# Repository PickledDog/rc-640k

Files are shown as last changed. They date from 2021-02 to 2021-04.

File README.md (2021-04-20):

# rc-640k
 128K+512K RAM/ROM card for RC2014
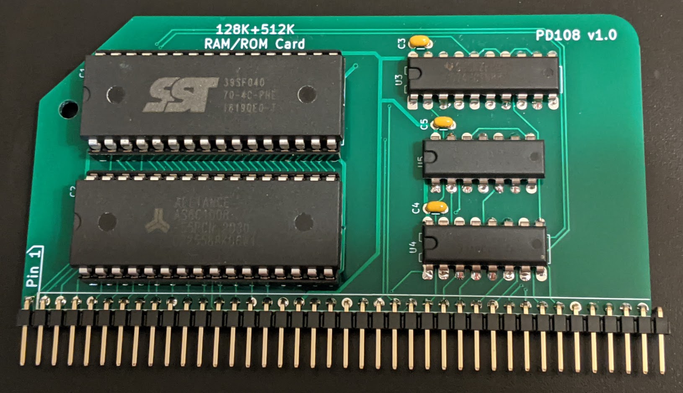
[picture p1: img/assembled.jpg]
Assembled PD108


## Overview
This RC2014-compatible board provides RAM and flash ROM, software-pageable in 32k pages. 16 ROM or 4 RAM pages may be paged into the lower 32k of Z80 memory. This paging scheme is compatible with Wayne Warthen's [RomWBW](https://github.com/wwarthen/RomWBW).

## Memory details
For ROM, a SST39SF040 512k x 8 flash chip is used. It can be programmed in-place using Will Sowerbutts' FLASH4 utility (included with RomWBW). For RAM, an AS6C1008 128k x 8 SRAM is used, providing 128K of addressable memory. Both are divided into 32k pages, and any page of either chip can be paged into the lower 32k of the address space. The upper 32k is permanently mapped to the last page of the RAM chip.

## Paging
Upon reset, the first page of the ROM is mapped to the lower 32k. If left alone, the board will behave like any 32k ROM+32k RAM RC2014 system. A config register is used to set the currently mapped page, presented as an I/O device at 0x78 (the address used by most "large" Z80 memory systems). The low nibble sets the page number (0-15 for ROM, 0-3 for RAM), and high bit 7 selects the chip (0 for ROM, 1 for RAM).

The port address and layout are chosen to be (mostly) compatible with the [RetroBrew SBC](https://www.retrobrewcomputers.org/doku.php?id=boards:sbc:sbc_v2:sbc_v2-003). The SBC has separate ROM and RAM registers (on 0x78 and 0x7C); this board uses a single register for both, which can be written to from either address.

## Firmware
Many [RC2014 ROM images](https://github.com/RC2014Z80/RC2014/tree/master/ROMs) can be used (selecting the right image for your serial board), but some will require modification to accommodate the different paging system. The 32k BASIC images work unmodified. Stephen C Cousins' excellent [Small Computer Monitor](https://smallcomputercentral.wordpress.com/small-computer-monitor/) can be used as well - choose the R3 configuration. CP/M loading *won't work* without code changes.

But most importantly, this board is compatible with [RomWBW](https://github.com/wwarthen/RomWBW), providing several CP/M versions, ROM applications, and maximized free application memory. It will need to be built from source with configuration changes, although this is fairly straightforward (RomWBW includes its entire build toolchain in the source tree). The build process is covered in [this page](https://github.com/wwarthen/RomWBW/blob/master/Source/ReadMe.txt) from the RomWBW documentation (including Linux and Mac instructions). An example image can be found in the [firmware](/firmware) directory.

### RomWBW Config changes
With the [source tree](https://github.com/wwarthen/RomWBW) unpacked, go into `Source/HBIOS/Config` and make a copy of `RCZ80_std.asm` (call it `RCZ80_pd.asm`). Edit this new file, and add the following lines:
```
RAMSIZE		.SET	128		; SIZE OF RAM IN KB (MUST MATCH YOUR HARDWARE!!!)
MEMMGR		.SET	MM_SBC		; MEMORY MANAGER: MM_[SBC|Z2|N8|Z180]
MPCL_RAM	.EQU	$78		; SBC MEM MGR RAM PAGE SELECT REG (WRITE ONLY)
MPCL_ROM	.EQU	$7C		; SBC MEM MGR ROM PAGE SELECT REG (WRITE ONLY)
;
```
As of RomWBW 3.1, it is possible to have a ROMdisk without a RAMdisk (which this board does not support). If building RomWBW 3.1 or later, add this line too: 
```
MDRAM		.SET	FALSE		; MD: DISABLE RAM DISK
;
```
With our new file, we can go ahead and build our ROM image. Under Windows, this is done with the following commands in `Source`:

* `BuildShared`
  * Wait for this to complete, ignoring the harmless program origin warnings
* `BuildROM`
  * Enter `RCZ80` at the *Platform* prompt
  * Enter `pd` at the *Configuration* prompt

Once the build is complete, we are done! Back at the root of the source tree, go into `Binary` and retrieve our new `RCZ80_pd.rom`. This can now be burned to the flash chip using an EPROM programmer, such as a [TL866](https://www.ebay.com/sch/i.html?_nkw=tl866ii+plus).

## Part selection
Bill Of Materials and part references are below. I recommend using gold-plated header for the bus connection - I use these ones from [Pololu](https://www.pololu.com/product/967) or [Sparkfun](https://www.sparkfun.com/products/553). A nice detail of these, is that they sit at the same height as double-row header in a backplane.

The specified parts are just the ones I used, and can be substituted as needed - Mouser links provided for convenience and reference.

| Reference | Value | Qty | Mouser link |
| --- | ----- | --- | --- |
| C1-C5 | 100nF ceramic | 5 | [KEMET C315C104M5U5TA](https://www.mouser.com/ProductDetail/C315C104M5U5TA7303) |
| J1 | 1x40 right-angle header | 1 | [Wurth 61304011021](https://www.mouser.com/ProductDetail/61304011021) |
| U1 | SST39SF040 NOR flash | 1 | [Microchip SST39SF040-70-4C-PHE](https://www.mouser.com/ProductDetail/SST39SF040-70-4C-PHE) |
| U2 | AS6C1008 SRAM | 1 | [Alliance AS6C1008-55PCN](https://www.mouser.com/ProductDetail/AS6C1008-55PCN) |
| | sockets | 2 | [Amphenol DILB32P-223TLF](https://www.mouser.com/ProductDetail/DILB32P-223TLF) |
| U3 | 74HCT688 | 1 | [TI CD74HCT688E](https://www.mouser.com/ProductDetail/CD74HCT688E) |
| U4 | 74HCT174 | 1 | [TI CD74HCT174E](https://www.mouser.com/ProductDetail/CD74HCT174E) |
| U5 | 74HCT32 | 1 | [TI SN74HCT32N](https://www.mouser.com/ProductDetail/SN74HCT32N) |

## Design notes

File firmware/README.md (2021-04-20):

# Firmware
This directory contains firmware source and binary for the board. As of now, it currently only contains a RomWBW image and the config file used to make it. It is currently built against RomWBW 3.1.1-pre.71.

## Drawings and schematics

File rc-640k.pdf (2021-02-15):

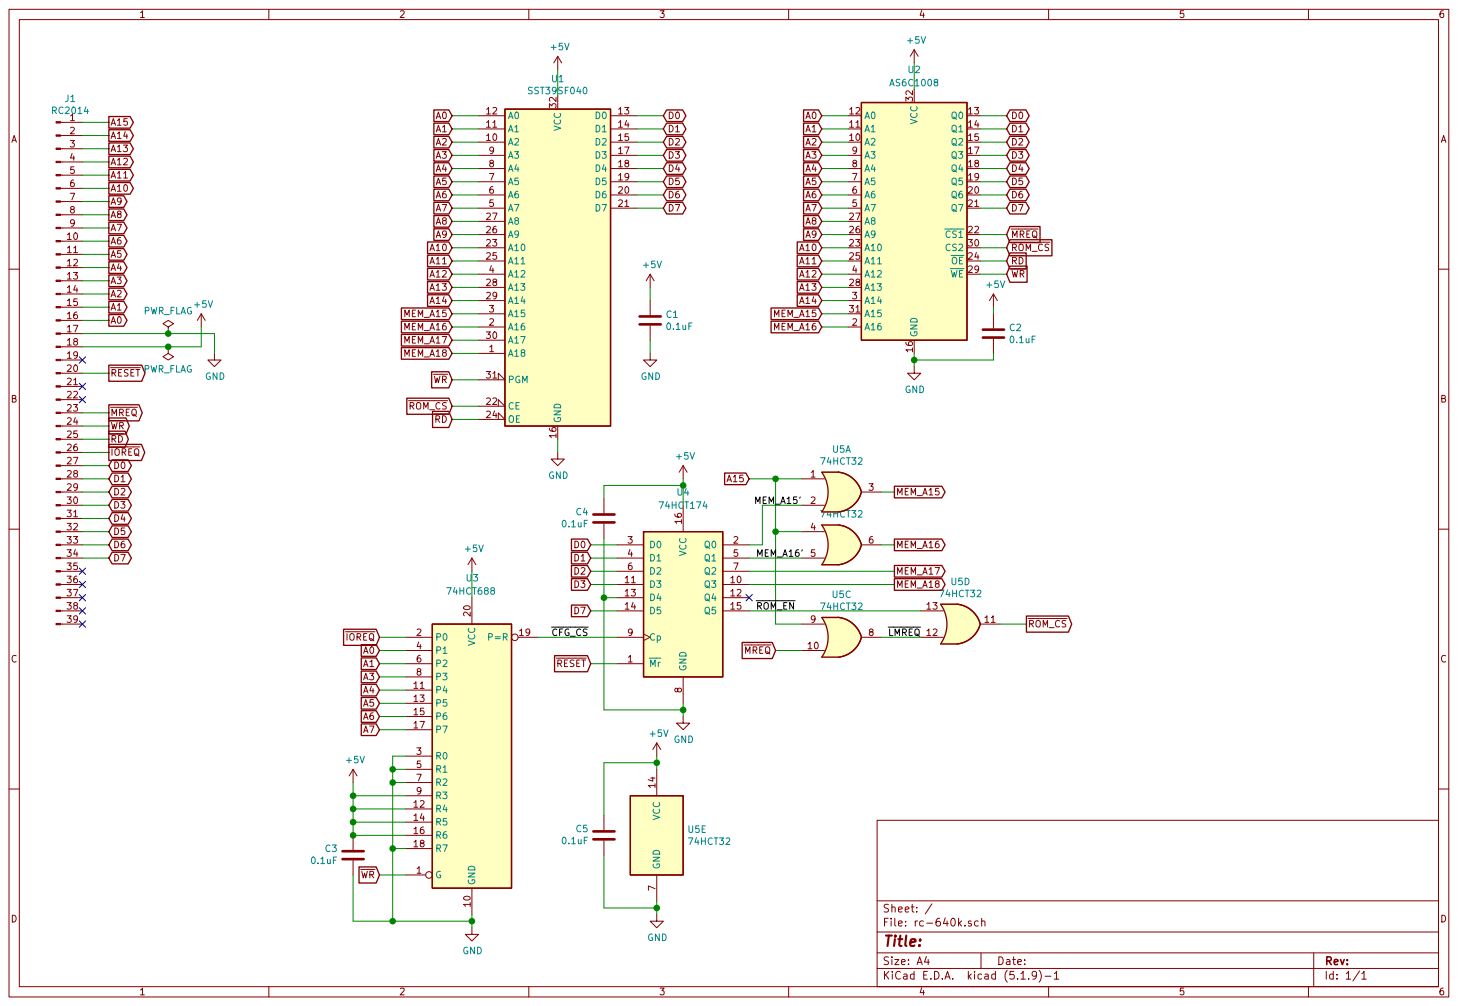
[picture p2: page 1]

Id: 1/1 Title: File: rc-640k.sch Sheet: / GND

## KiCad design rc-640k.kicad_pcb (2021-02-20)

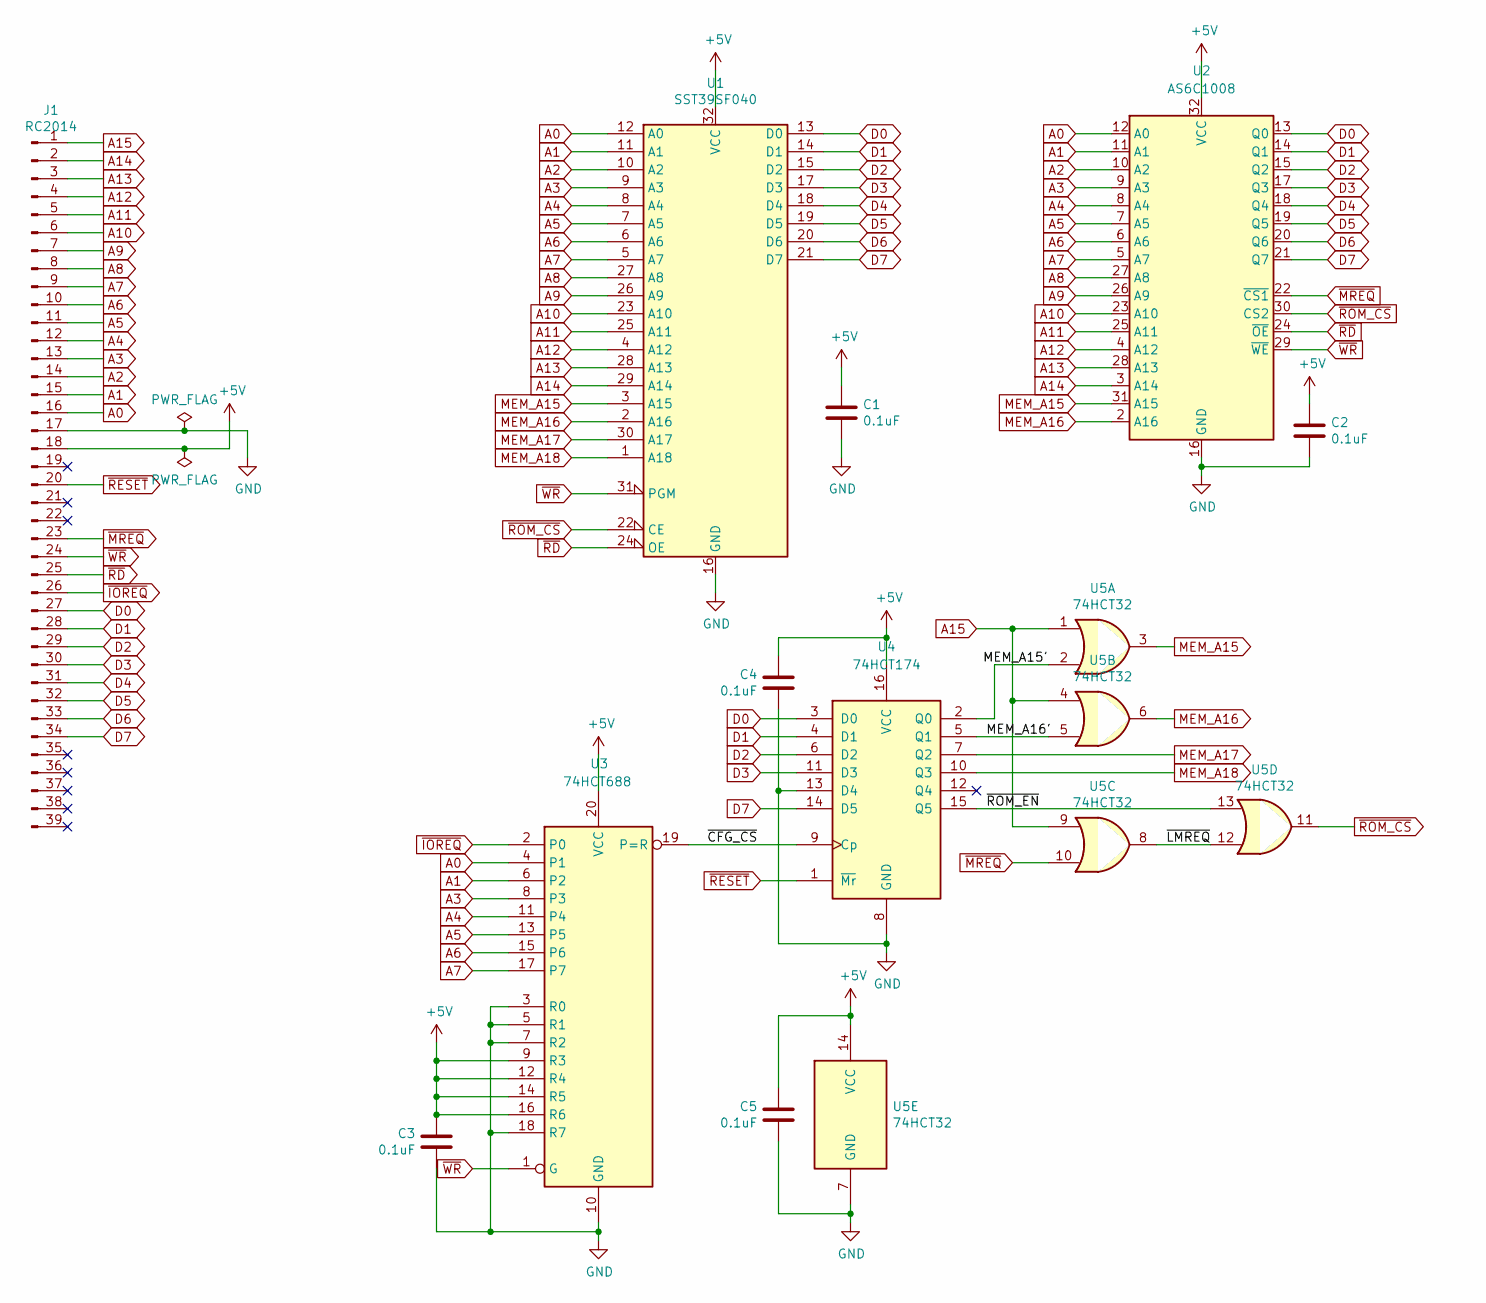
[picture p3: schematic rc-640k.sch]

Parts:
C1, C2, C3, C4, C5: 0.1uF; C_Disc_D3.0mm_W1.6mm_P2.50mm
J1: RC2014; PinHeader_1x39_P2.54mm_Vertical
U1: SST39SF040; DIP-32_W15.24mm_LongPads
U2: AS6C1008; DIP-32_W15.24mm_LongPads
U3: 74HCT688; DIP-20_W7.62mm_LongPads
U4: 74HCT174; DIP-16_W7.62mm_LongPads
U5: 74HCT32; DIP-14_W7.62mm_LongPads

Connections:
+5V: C1.1, C2.1, C3.2, C4.2, C5.2, J1.18, U1.32 (VCC), U2.32 (VCC), U3.9 (R3), U3.12 (R4), U3.14 (R5), U3.16 (R6), U3.20 (VCC), U4.16 (VCC), U5.14 (VCC)
/MEM_A15': U4.2 (Q0), U5.2
/MEM_A16': U4.5 (Q1), U5.5
/~CFG_CS: U3.19 (P=R), U4.9 (Cp)
/~LMREQ: U5.8, U5.12
/~ROM_EN: U4.15 (Q5), U5.13
A0: J1.16, U1.12 (A0), U2.12 (A0), U3.4 (P1)
A1: J1.15, U1.11 (A1), U2.11 (A1), U3.6 (P2)
A2: J1.14, U1.10 (A2), U2.10 (A2)
A3: J1.13, U1.9 (A3), U2.9 (A3), U3.8 (P3)
A4: J1.12, U1.8 (A4), U2.8 (A4), U3.11 (P4)
A5: J1.11, U1.7 (A5), U2.7 (A5), U3.13 (P5)
A6: J1.10, U1.6 (A6), U2.6 (A6), U3.15 (P6)
A7: J1.9, U1.5 (A7), U2.5 (A7), U3.17 (P7)
A8: J1.8, U1.27 (A8), U2.27 (A8)
A9: J1.7, U1.26 (A9), U2.26 (A9)
A10: J1.6, U1.23 (A10), U2.23 (A10)
A11: J1.5, U1.25 (A11), U2.25 (A11)
A12: J1.4, U1.4 (A12), U2.4 (A12)
A13: J1.3, U1.28 (A13), U2.28 (A13)
A14: J1.2, U1.29 (A14), U2.3 (A14)
A15: J1.1, U5.1, U5.4, U5.9
D0: J1.27, U1.13 (D0), U2.13 (Q0), U4.3 (D0)
D1: J1.28, U1.14 (D1), U2.14 (Q1), U4.4 (D1)
D2: J1.29, U1.15 (D2), U2.15 (Q2), U4.6 (D2)
D3: J1.30, U1.17 (D3), U2.17 (Q3), U4.11 (D3)
D4: J1.31, U1.18 (D4), U2.18 (Q4)
D5: J1.32, U1.19 (D5), U2.19 (Q5)
D6: J1.33, U1.20 (D6), U2.20 (Q6)
D7: J1.34, U1.21 (D7), U2.21 (Q7), U4.14 (D5)
GND: C1.2, C2.2, C3.1, C4.1, C5.1, J1.17, U1.16 (GND), U2.16 (GND), U3.3 (R0), U3.5 (R1), U3.7 (R2), U3.10 (GND), U3.18 (R7), U4.8 (GND), U4.13 (D4), U5.7 (GND)
MEM_A15: U1.3 (A15), U2.31 (A15), U5.3
MEM_A16: U1.2 (A16), U2.2 (A16), U5.6
MEM_A17: U1.30 (A17), U4.7 (Q2)
MEM_A18: U1.1 (A18), U4.10 (Q3)
~IOREQ: J1.26, U3.2 (P0)
~MREQ: J1.23, U2.22 (~CS1), U5.10
~RD: J1.25, U1.24 (OE), U2.24 (~OE)
~RESET: J1.20, U4.1 (~Mr)
~ROM_CS: U1.22 (CE), U2.30 (CS2), U5.11
~WR: J1.24, U1.31 (PGM), U2.29 (~WE), U3.1 (G)

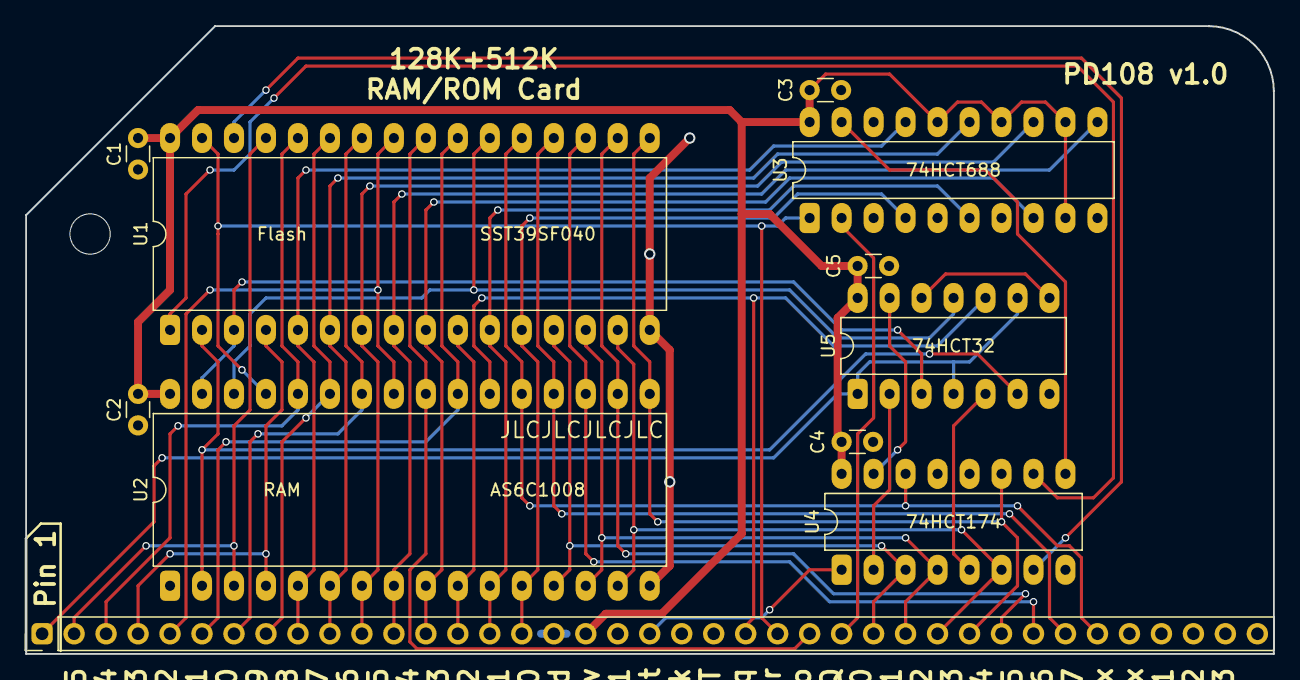
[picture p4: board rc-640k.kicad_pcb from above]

Board: 2 copper layers, 99.1 x 49.9 mm, 11 parts (0 on the bottom side), 41 nets.

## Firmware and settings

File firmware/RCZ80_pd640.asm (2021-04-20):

;
;==================================================================================================
;   RC2014 Z80 PD640 CONFIGURATION
;==================================================================================================
;
; THE COMPLETE SET OF DEFAULT CONFIGURATION SETTINGS FOR THIS PLATFORM ARE FOUND IN THE
; CFG_<PLT>.ASM INCLUDED FILE WHICH IS FOUND IN THE PARENT DIRECTORY.  THIS FILE CONTAINS
; COMMON CONFIGURATION SETTINGS THAT OVERRIDE THE DEFAULTS.  IT IS INTENDED THAT YOU MAKE
; YOUR CUSTOMIZATIONS IN THIS FILE AND JUST INHERIT ALL OTHER SETTINGS FROM THE DEFAULTS.
; EVEN BETTER, YOU CAN MAKE A COPY OF THIS FILE WITH A NAME LIKE <PLT>_XXX.ASM AND SPECIFY
; YOUR FILE IN THE BUILD PROCESS.
;
; THE SETTINGS BELOW ARE THE SETTINGS THAT ARE MOST COMMONLY MODIFIED FOR THIS PLATFORM.
; MANY OF THEM ARE EQUAL TO THE SETTINGS IN THE INCLUDED FILE, SO THEY DON'T REALLY DO
; ANYTHING AS IS.  THEY ARE LISTED HERE TO MAKE IT EASY FOR YOU TO ADJUST THE MOST COMMON
; SETTINGS.
;
; N.B., SINCE THE SETTINGS BELOW ARE REDEFINING VALUES ALREADY SET IN THE INCLUDED FILE,
; TASM INSISTS THAT YOU USE THE .SET OPERATOR AND NOT THE .EQU OPERATOR BELOW. ATTEMPTING
; TO REDEFINE A VALUE WITH .EQU BELOW WILL CAUSE TASM ERRORS!
;
; PLEASE REFER TO THE CUSTOM BUILD INSTRUCTIONS (README.TXT) IN THE SOURCE DIRECTORY (TWO
; DIRECTORIES ABOVE THIS ONE).
;
#DEFINE	BOOT_DEFAULT	"H"		; DEFAULT BOOT LOADER CMD ON <CR> OR AUTO BOOT
;
#include "cfg_rcz80.asm"
;
CRTACT		.SET	FALSE		; ACTIVATE CRT (VDU,CVDU,PROPIO,ETC) AT STARTUP
;
CPUOSC		.SET	7372800		; CPU OSC FREQ IN MHZ
;
RAMSIZE		.SET	128		; SIZE OF RAM IN KB (MUST MATCH YOUR HARDWARE!!!)
MEMMGR		.SET	MM_SBC		; MEMORY MANAGER: MM_[SBC|Z2|N8|Z180]
MPCL_RAM	.EQU	$78		; SBC MEM MGR RAM PAGE SELECT REG (WRITE ONLY)
MPCL_ROM	.EQU	$7C		; SBC MEM MGR ROM PAGE SELECT REG (WRITE ONLY)
;
UARTENABLE	.SET	TRUE		; UART: ENABLE 8250/16550-LIKE SERIAL DRIVER (UART.ASM)
ACIAENABLE	.SET	TRUE		; ACIA: ENABLE MOTOROLA 6850 ACIA DRIVER (ACIA.ASM)
SIOENABLE	.SET	TRUE		; SIO: ENABLE ZILOG SIO SERIAL DRIVER (SIO.ASM)
;
TMSENABLE	.SET	FALSE		; TMS: ENABLE TMS9918 VIDEO/KBD DRIVER (TMS.ASM)
TMSTIMENABLE	.SET	FALSE		; TMS: ENABLE TIMER INTERRUPTS (REQUIRES IM1)
;
MDRAM		.SET	FALSE		; MD: DISABLE RAM DISK
;
FDENABLE	.SET	FALSE		; FD: ENABLE FLOPPY DISK DRIVER (FD.ASM)
FDMODE		.SET	FDMODE_RCWDC	; FD: DRIVER MODE: FDMODE_[DIO|ZETA|ZETA2|DIDE|N8|DIO3|RCSMC|RCWDC|DYNO|EPWDC]
;
IDEENABLE	.SET	TRUE		; IDE: ENABLE IDE DISK DRIVER (IDE.ASM)
;
PPIDEENABLE	.SET	TRUE		; PPIDE: ENABLE PARALLEL PORT IDE DISK DRIVER (PPIDE.ASM)
;
PRPENABLE	.SET	FALSE		; PRP: ENABLE ECB PROPELLER IO BOARD DRIVER (PRP.ASM)

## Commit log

2021-02-15 Initial commit of rc-640k/PD108
    [rc-640k-B_Cu.gbr, rc-640k-B_Mask.gbr, rc-640k-B_SilkS.gbr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]
2021-02-18 Move to v1.0
    Neaten up board, improve ground plane
    [rc-640k-B_Cu.gbr, rc-640k-B_Mask.gbr, rc-640k-B_SilkS.gbr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]
2021-02-20 Tweak routing
    [rc-640k-B_Cu.gbr, rc-640k-B_Mask.gbr, rc-640k-B_SilkS.gbr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]
2021-03-16 Update picture to current version
